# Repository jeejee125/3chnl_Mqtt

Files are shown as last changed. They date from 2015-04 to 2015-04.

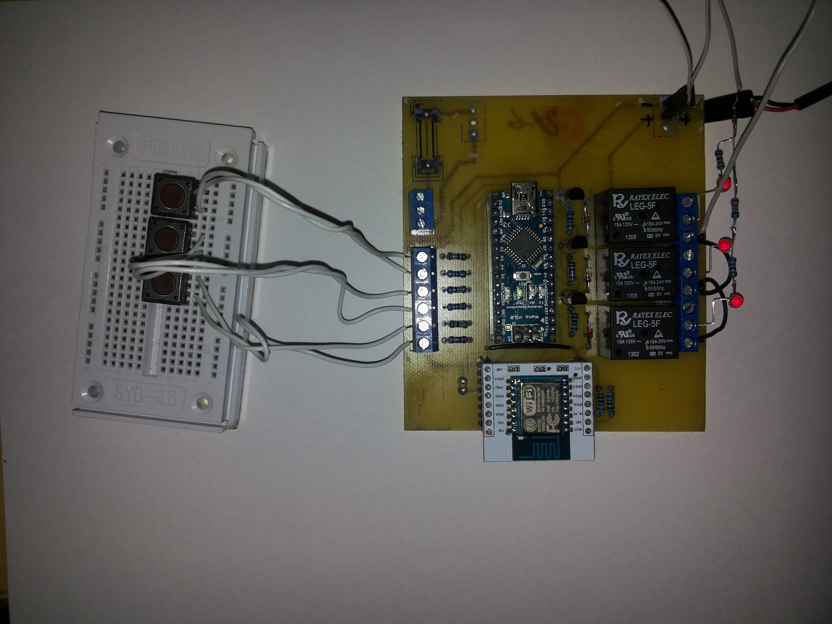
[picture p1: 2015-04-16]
Eagle/mqttlightctrl.jpg

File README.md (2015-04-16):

3 channel mqtt client switch for homeautomation. example usage for lights contoll at openhab

Hardware:

ESP8266 -12 
http://www.dx.com/p/esp-12-esp8266-serial-wifi-wireless-module-w-pcb-antenna-adapter-board-for-arduino-raspberry-pi-379296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
Arduino nano:
http://www.dx.com/p/arduino-nano-v3-0-81877#.VS9lat9Pq0w

custmo made i/o board chematic and bcp under directory /Eagle

- Product: Program Connection diagram

Sofware :

ESP8266 

https://github.com/tuanpmt/espduino/

Arduino:

modifiet tuanpmt exaple of MQTT client

Example for MQTT client
=======

```c 

/**
 * \file
 *       ESP8266 MQTT Bridge example
 * \
 *       >
 */
#include <SoftwareSerial.h>
#include <espduino.h>
#include <mqtt.h>
int switchPinA = 6;   // switch is connected to pin 2
int switchPinB = 7;
int switchPinC = 8;
int ledPinA = 12;
int ledPinB = 11;
int ledPinC = 10;
int switchPin;
int led1Pin;
int val;                         // variable for reading the pin status
int val2;                       // variable for reading the delayed/debounced status
int abuttonState;                // variable to hold the button state
int bbuttonState;
int cbuttonState;
int lightModea = 0;
int lightModeb = 0;
int lightModec = 0;
SoftwareSerial debugPort(2, 3); // RX, TX
ESP esp(&Serial, &debugPort, 4);
MQTT mqtt(&esp);
boolean wifiConnected = false;

void wifiCb(void* response)
{
  uint32_t status;
  RESPONSE res(response);

  if(res.getArgc() == 1) {
    res.popArgs((uint8_t*)&status, 4);
    if(status == STATION_GOT_IP) {
      debugPort.println("WIFI CONNECTED");
      mqtt.connect("ip.of.mqtt.broker", 1883, false);
      wifiConnected = true;
      //or mqtt.connect("host", 1883); /*without security ssl*/
    } else {
      wifiConnected = false;
      mqtt.disconnect();
    }

  }
}

void mqttConnected(void* response)
{
  debugPort.println("Connected");
  mqtt.subscribe("/home/1/esp01/p1/com"); //or mqtt.subscribe("topic"); /*with qos = 0*/
  mqtt.subscribe("/home/1/esp01/p2/com");
  mqtt.subscribe("/home/1/esp01/p3/com");
  mqtt.publish("/home/1/esp01/p1/com", "data0");
  mqtt.publish("/home/1/esp01/p2/com", "data0");
  mqtt.publish("/home/1/esp01/p3/com", "data0");

}
void mqttDisconnected(void* response)
{

}
void mqttData(void* response)
{
  RESPONSE res(response);

  debugPort.print("Received: topic=");
  String topic = res.popString();
  debugPort.println(topic);

  debugPort.print("data=");
  String data = res.popString();
  debugPort.println(data);
  
  if (topic == "/home/1/esp01/p1/com"){

   if (data == "ON") {                // check if the button is pressed
        if (lightModea == 0) {          // is the light off?
          lightModea = 1;               // turn light on!
          digitalWrite(ledPinA, HIGH);
         // mqtt.publish("/home/1/esp01/p1/state","ON",0,0);
       
        } 
   }
   if (data == "OFF")      {
     if (lightModea == 1){
          lightModea = 0;               // turn light off!
          digitalWrite(ledPinA, LOW);
          // mqtt.publish("/home/1/esp01/p1/state","OFF",0,0);
         }
      }
  }
    if (topic == "/home/1/esp01/p2/com"){

   if (data == "ON") {                // check if the button is pressed
        if (lightModeb == 0) {          // is the light off?
          lightModeb = 1;               // turn light on!
          digitalWrite(ledPinB, HIGH);
         // mqtt.publish("/home/1/esp01/p1/state","ON",0,0);
       
        } 
   }
   if (data == "OFF")      {
     if (lightModeb == 1){
          lightModeb = 0;               // turn light off!
          digitalWrite(ledPinB, LOW);
          // mqtt.publish("/home/1/esp01/p1/state","OFF",0,0);
         }
      }
  }
  if (topic == "/home/1/esp01/p3/com"){

   if (data == "ON") {                // check if the button is pressed
        if (lightModec == 0) {          // is the light off?
          lightModec = 1;               // turn light on!
          digitalWrite(ledPinC, HIGH);
         // mqtt.publish("/home/1/esp01/p1/state","ON",0,0);
       
        } 
   }
   if (data == "OFF")      {
     if (lightModec == 1){
          lightModec = 0;               // turn light off!
          digitalWrite(ledPinC, LOW);
          // mqtt.publish("/home/1/esp01/p1/state","OFF",0,0);
         }
      }
  }
}
void mqttPublished(void* response)
{

}
void setup() {
  Serial.begin(19200);
  debugPort.begin(19200);
  esp.enable();
  delay(500);
  esp.reset();
  delay(500);
  while(!esp.ready());
  pinMode(switchPinA, INPUT);    // Set the switch pin as input
  pinMode(switchPinB, INPUT);    // Set the switch pin as input
  pinMode(switchPinC, INPUT);    // Set the switch pin as input
  pinMode(ledPinA, OUTPUT);
  pinMode(ledPinB, OUTPUT);
  pinMode(ledPinC, OUTPUT);
  debugPort.println("ARDUINO: setup mqtt client");
  if(!mqtt.begin("esp01", "admin", "Isb_C4OGD4c3", 120, 1)) {
    debugPort.println("ARDUINO: fail to setup mqtt");
    while(1);
  }

  debugPort.println("ARDUINO: setup mqtt lwt");
  mqtt.lwt("/lwt", "offline", 0, 0); //or mqtt.lwt("/lwt", "offline");

/*setup mqtt events */
  mqtt.connectedCb.attach(&mqttConnected);
  mqtt.disconnectedCb.attach(&mqttDisconnected);
  mqtt.publishedCb.attach(&mqttPublished);
  mqtt.dataCb.attach(&mqttData);

  /*setup wifi*/
  debugPort.println("ARDUINO: setup wifi");
  esp.wifiCb.attach(&wifiCb);

  esp.wifiConnect("wifiSSID","wifipasswd");

  debugPort.println("ARDUINO: system started");
}

void loop() {
  esp.process();
  if(wifiConnected) {
  switcheesA();
  switcheesB();
  switcheesC();
 // lights();  
 
  }
}

 void switcheesA(){
   val = digitalRead(switchPinA);   // read input value and store it in val
     delay(10);
 //    switchPin = switchPinA;
     val2 = digitalRead(switchPinA);

           // read the input again to check for bounces
  if (val == val2) {                 // make sure we got 2 consistant readings!
   if (val != abuttonState) {          // the button state has changed!
      if (val == LOW) {         // check if the button is pressed
          led1Pin = ledPinA;
        if (lightModea == 0) {          // is the light off?
          lightModea = 1;               // turn light on!
          digitalWrite(led1Pin, HIGH);
          mqtt.publish("/home/1/esp01/p1/state","ON",0,0);
       
        } else {
          lightModea = 0;               // turn light off!
          digitalWrite(led1Pin, LOW);
           mqtt.publish("/home/1/esp01/p1/state","OFF",0,0);
         }
      }
    }
  }
    abuttonState = val;

    } 
 
   void switcheesB(){
   val = digitalRead(switchPinB);   // read input value and store it in val
     delay(10);
     switchPin = switchPinB;
     val2 = digitalRead(switchPin);
      
     led1Pin = ledPinB;
    
           // read the input again to check for bounces
  if (val == val2) {                 // make sure we got 2 consistant readings!
   if (val != bbuttonState) {          // the button state has changed!
      if (val == LOW) {                // check if the button is pressed
        if (lightModeb == 0) {          // is the light off?
          lightModeb = 1;               // turn light on!
          digitalWrite(led1Pin, HIGH);
          mqtt.publish("/home/1/esp01/p2/state","ON",0,0);
       
        } else {
          lightModeb = 0;               // turn light off!
          digitalWrite(led1Pin, LOW);
           mqtt.publish("/home/1/esp01/p2/state","OFF",0,0);
         }
      }
    }
  }
    bbuttonState = val;

    } 
  
    void switcheesC(){
   val = digitalRead(switchPinC);   // read input value and store it in val
     delay(10);
     switchPin = switchPinC;
     val2 = digitalRead(switchPin);
      
     led1Pin = ledPinC;
    
           // read the input again to check for bounces
  if (val == val2) {                 // make sure we got 2 consistant readings!
   if (val != cbuttonState) {          // the button state has changed!
      if (val == LOW) {                // check if the button is pressed
        if (lightModec == 0) {          // is the light off?
          lightModec = 1;               // turn light on!
          digitalWrite(led1Pin, HIGH);
          mqtt.publish("/home/1/esp01/p3/state","ON",0,0);
       
        } else {
          lightModec = 0;               // turn light off!
          digitalWrite(led1Pin, LOW);
           mqtt.publish("/home/1/esp01/p3/state","OFF",0,0);
         }
      }
    }
  }
    cbuttonState = val;

    } 

```

Openhab & mosquitto & & & :
=======

Add the OpenHab Repository
```bash
sudo nano /etc/apt/sources.list.d/openhab.list
```
Insert:
```bash
 deb http://repository-openhab.forge.cloudbees.com/release/1.6.2/apt-repo/ /
```
Install Java
```bash
echo "deb http://ppa.launchpad.net/webupd8team/java/ubuntu trusty main" | tee /etc/apt/sources.list.d/webupd8team-java.list
echo "deb-src http://ppa.launchpad.net/webupd8team/java/ubuntu trusty main" | tee -a /etc/apt/sources.list.d/webupd8team-java.list
apt-get install oracle-java8-installer
```
Install OpenHAB
```bash
sudo apt-get install openhab-runtime openhab-addon-binding-mqtt openhab-addon-action-mail openhab-addon-binding-bluetooth openhab-addon-binding-serial openhab-addon-binding-weather openhab-addon-persistence-rrd4j
```

Install Mosquitto
```bash
sudo apt-add-repository ppa:mosquitto-dev/mosquitto-ppa
sudo apt-get install mosquitto mosquitto-clients
```
Start and Test Mosquitto
```bash
sudo /etc/init.d/mosquitto start
```
Configure OpenHAB to use a MQTT Binding
```bash
sudo nano /etc/openhab/configurations/openhab_default.cfg
```
At the very bottom, define a MQTT Broker:
```bash
mqtt:broker.url=tcp://192.168.1.100:1883
mqtt:broker.clientId=openhab
Exit, Save,  
```
restart OpenHAB
```bash
sudo /etc/init.d/openhab restart
```
```bash
sudo nano /etc/openhab/configurations/sitemaps/home.sitemap

sitemap demo label="Main Menu"
{
 Frame label="MQTT" {
   Switch item=lamp1 label="Lampa"
   Switch item=lamp2 label="Lampb"
   Switch item=lamp3 label="Lampc"
 }
}
```
```bash
sudo nano /etc/openhab/configurations/items/home.items

Switch lamp1 "Lampa" (all){mqtt=">[broker:/home/1/esp01/p1/com:command:on:ON],>[broker:/home/1/esp01/p1/com:command:off:OFF],<[broker:/home/1/esp01/p1/state:state:default]"}
Switch lamp2 "Lampb" (all){mqtt=">[broker:/home/1/esp01/p2/com:command:on:ON],>[broker:/home/1/esp01/p2/com:command:off:OFF],<[broker:/home/1/esp01/p2/state:state:default]"}
Switch lamp3 "Lampc" (all){mqtt=">[broker:/home/1/esp01/p3/com:command:on:ON],>[broker:/home/1/esp01/p3/com:command:off:OFF],<[broker:/home/1/esp01/p3/state:state:default]"}
```
```bash
sudo /etc/init.d/openhab restart

browser:

http://192.168.1.100:8080/openhab.app?sitemap=home

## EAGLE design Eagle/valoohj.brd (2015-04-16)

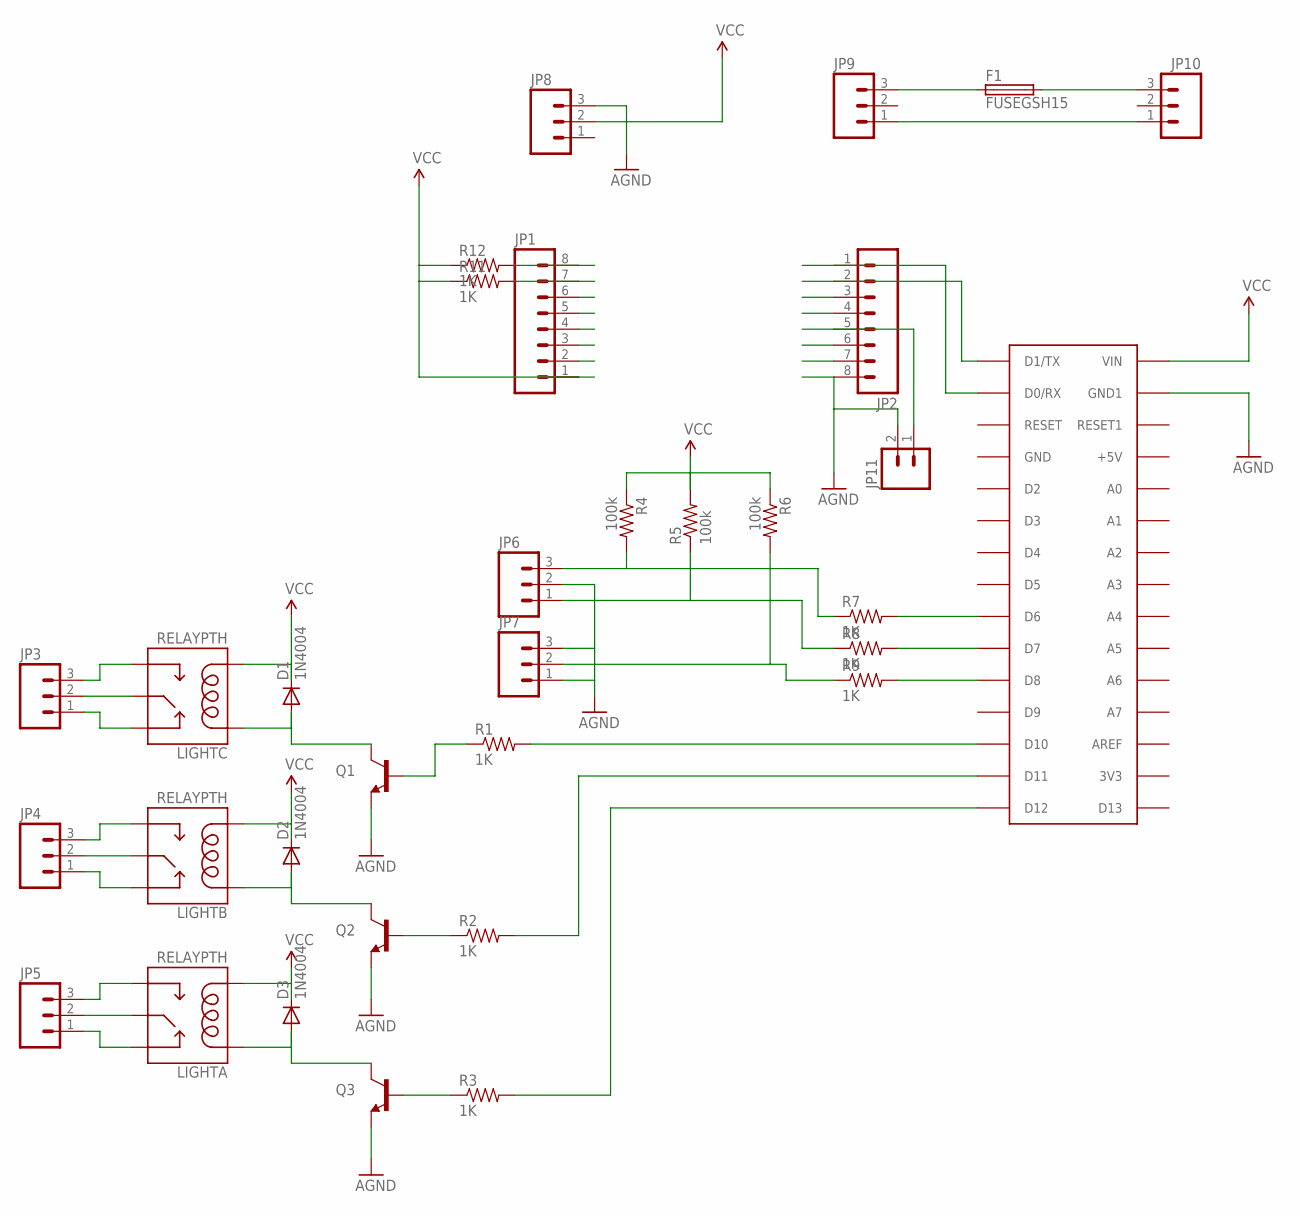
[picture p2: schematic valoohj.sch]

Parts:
D1, D2, D3: 1N4004; DO41-10
F1: FUSEGSH15; GSH15
JP1, JP2: M08LONGPADS; 1X08_LONGPADS
JP3, JP4, JP5, JP6, JP7: M03-SCREW-5MM; SCREWTERMINAL-5MM-3
JP8, JP9, JP10: M03SCREW; SCREWTERMINAL-3.5MM-3
JP11: M02LOCK; 1X02_LOCK
LIGHTA: RELAYPTH; SRD-05VDC-SL-C
LIGHTB: RELAYPTH; SRD-05VDC-SL-C
LIGHTC: RELAYPTH; SRD-05VDC-SL-C
Q1, Q2, Q3: TRANSISTOR_NPNBC547; TO-92-AMMO
R1, R2, R3, R7, R8, R9, R11, R12: 1K; AXIAL-0.3
R4, R5, R6: 100k; AXIAL-0.3
U$2: ARDUINONANO; PDIP-32

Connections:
AGND: JP2.8, JP6.2, JP7.1, JP7.3, JP8.3, JP11.2, Q1.3 (E), Q2.3 (E), Q3.3 (E), U$2.GND1
unnamed: R2.P$2 (2), U$2.D11
unnamed: F1.2, JP10.3
unnamed: F1.1, JP9.3
unnamed: JP9.1, JP10.1
unnamed: JP1.8, R12.P$2 (2)
unnamed: JP1.7, R11.P$2 (2)
unnamed: D1.A, LIGHTC.COIL1, Q1.1 (C)
unnamed: JP2.1, U$2.D0/RX
unnamed: JP2.2, U$2.D1/TX
unnamed: JP2.5, JP11.1
unnamed: D2.A, LIGHTB.COIL1, Q2.1 (C)
unnamed: R1.P$2 (2), U$2.D10
unnamed: Q1.2 (B), R1.P$1 (1)
unnamed: D3.A, LIGHTA.COIL1, Q3.1 (C)
unnamed: R9.P$2 (2), U$2.D8
unnamed: Q2.2 (B), R2.P$1 (1)
unnamed: Q3.2 (B), R3.P$1 (1)
unnamed: R3.P$2 (2), U$2.D12
unnamed: R8.P$2 (2), U$2.D7
unnamed: R7.P$2 (2), U$2.D6
unnamed: JP6.3, R4.P$2 (2), R7.P$1 (1)
unnamed: JP6.1, R5.P$1 (1), R8.P$1 (1)
unnamed: JP7.2, R6.P$2 (2), R9.P$1 (1)
unnamed: JP3.3, LIGHTC.SWOPEN
unnamed: JP3.2, LIGHTC.SWCOMMON
unnamed: JP3.1, LIGHTC.SWCLOSED (SWCLOSE)
unnamed: JP4.3, LIGHTB.SWOPEN
unnamed: JP4.2, LIGHTB.SWCOMMON
unnamed: JP4.1, LIGHTB.SWCLOSED (SWCLOSE)
unnamed: JP5.3, LIGHTA.SWOPEN
unnamed: JP5.2, LIGHTA.SWCOMMON
unnamed: JP5.1, LIGHTA.SWCLOSED (SWCLOSE)
VCC: D1.C, D2.C, D3.C, JP1.1, JP8.2, LIGHTA.COIL0, LIGHTB.COIL0, LIGHTC.COIL0, R4.P$1 (1), R5.P$2 (2), R6.P$1 (1), R11.P$1 (1), R12.P$1 (1), U$2.VIN

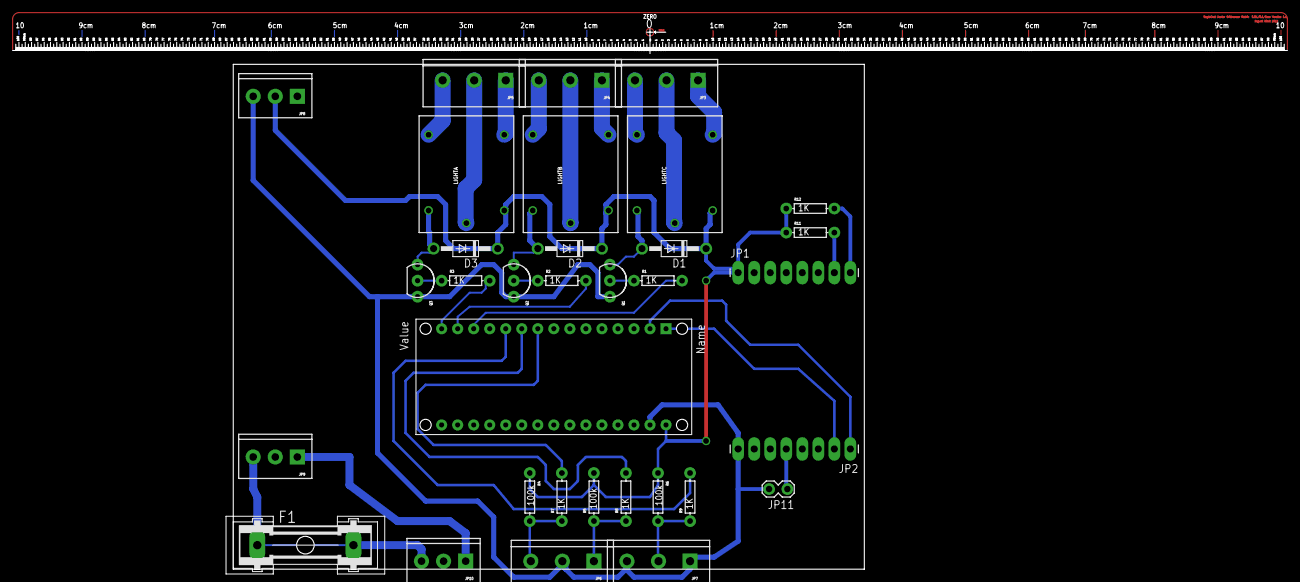
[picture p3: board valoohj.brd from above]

Board: 2 copper layers, 100.0 x 80.0 mm, 34 parts (0 on the bottom side), 34 nets.

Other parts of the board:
U$4: RULER

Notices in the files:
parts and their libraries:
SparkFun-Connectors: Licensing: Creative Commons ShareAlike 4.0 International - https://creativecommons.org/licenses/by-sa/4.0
